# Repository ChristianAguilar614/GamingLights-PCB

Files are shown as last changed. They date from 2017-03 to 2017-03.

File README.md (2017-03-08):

# GamingLights-PCB
Arduino Nano Shield

Circuit utilizes the compact size of the Arduino Nano to round appropriate light controllers. This works as an accent lighting system with RGB custimization. 
MOSFET drivers help boost the current and voltage which will be used to amplifier the overall wattage of the system to support 24 watts

#3d View
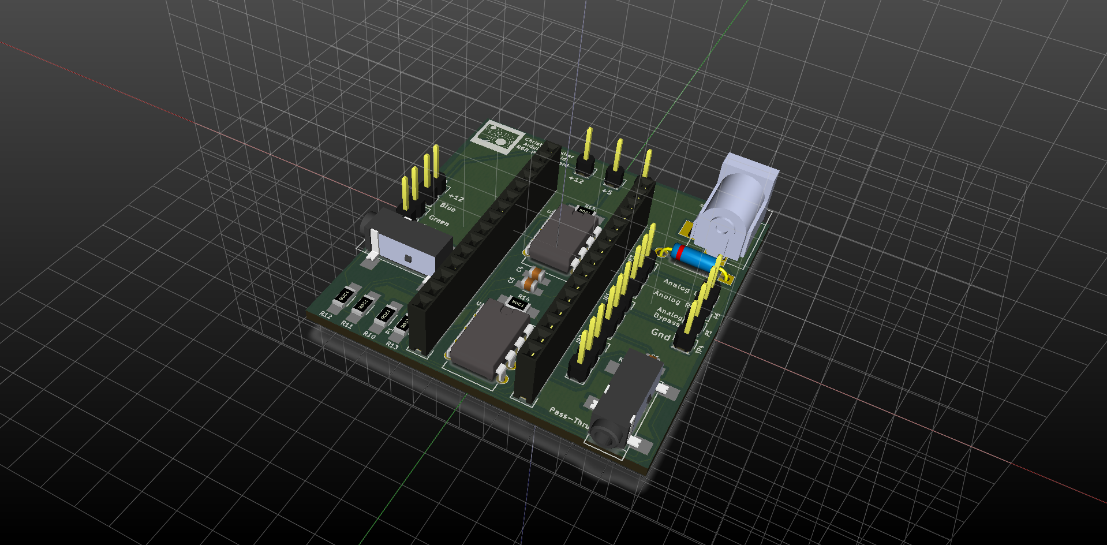
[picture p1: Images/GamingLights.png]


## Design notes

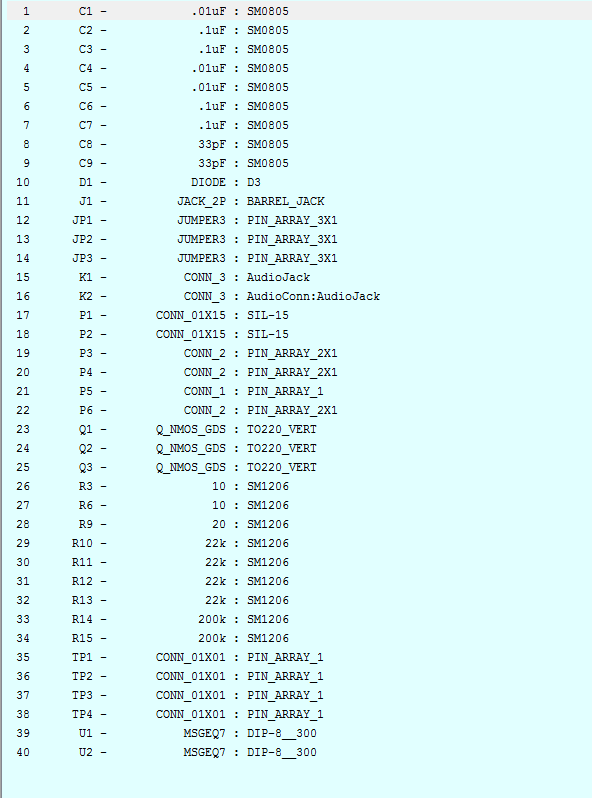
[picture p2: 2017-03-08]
Images/Comp2Part.PNG

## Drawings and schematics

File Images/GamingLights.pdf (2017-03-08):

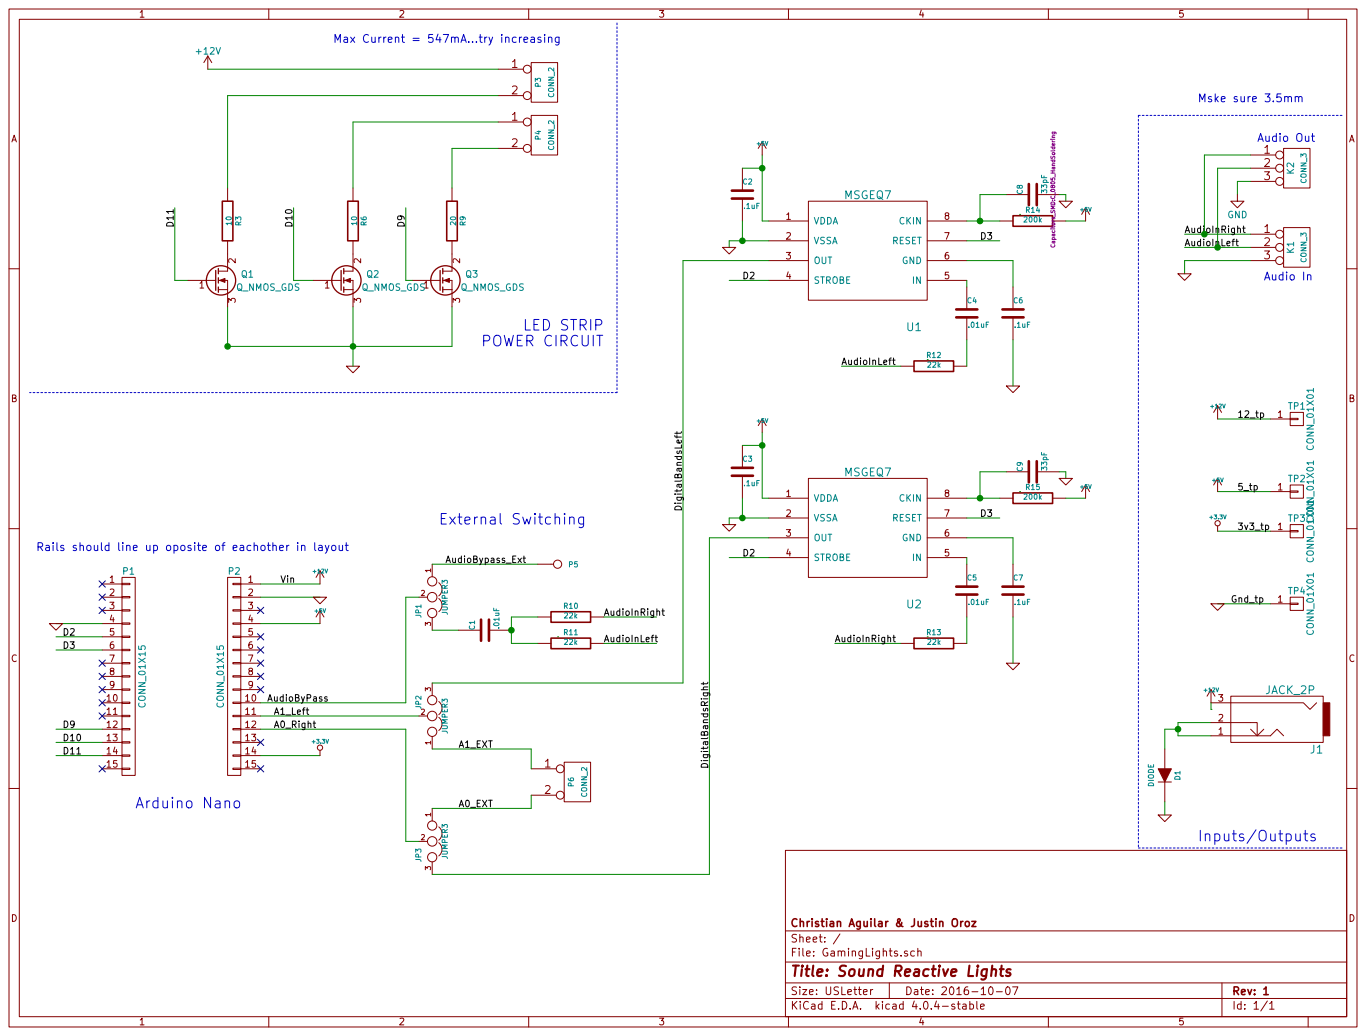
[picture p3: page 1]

Max Current = 547mA...try increasing

Audio Out Audio In GND

Id: 1/1 Title: Sound Reactive Lights

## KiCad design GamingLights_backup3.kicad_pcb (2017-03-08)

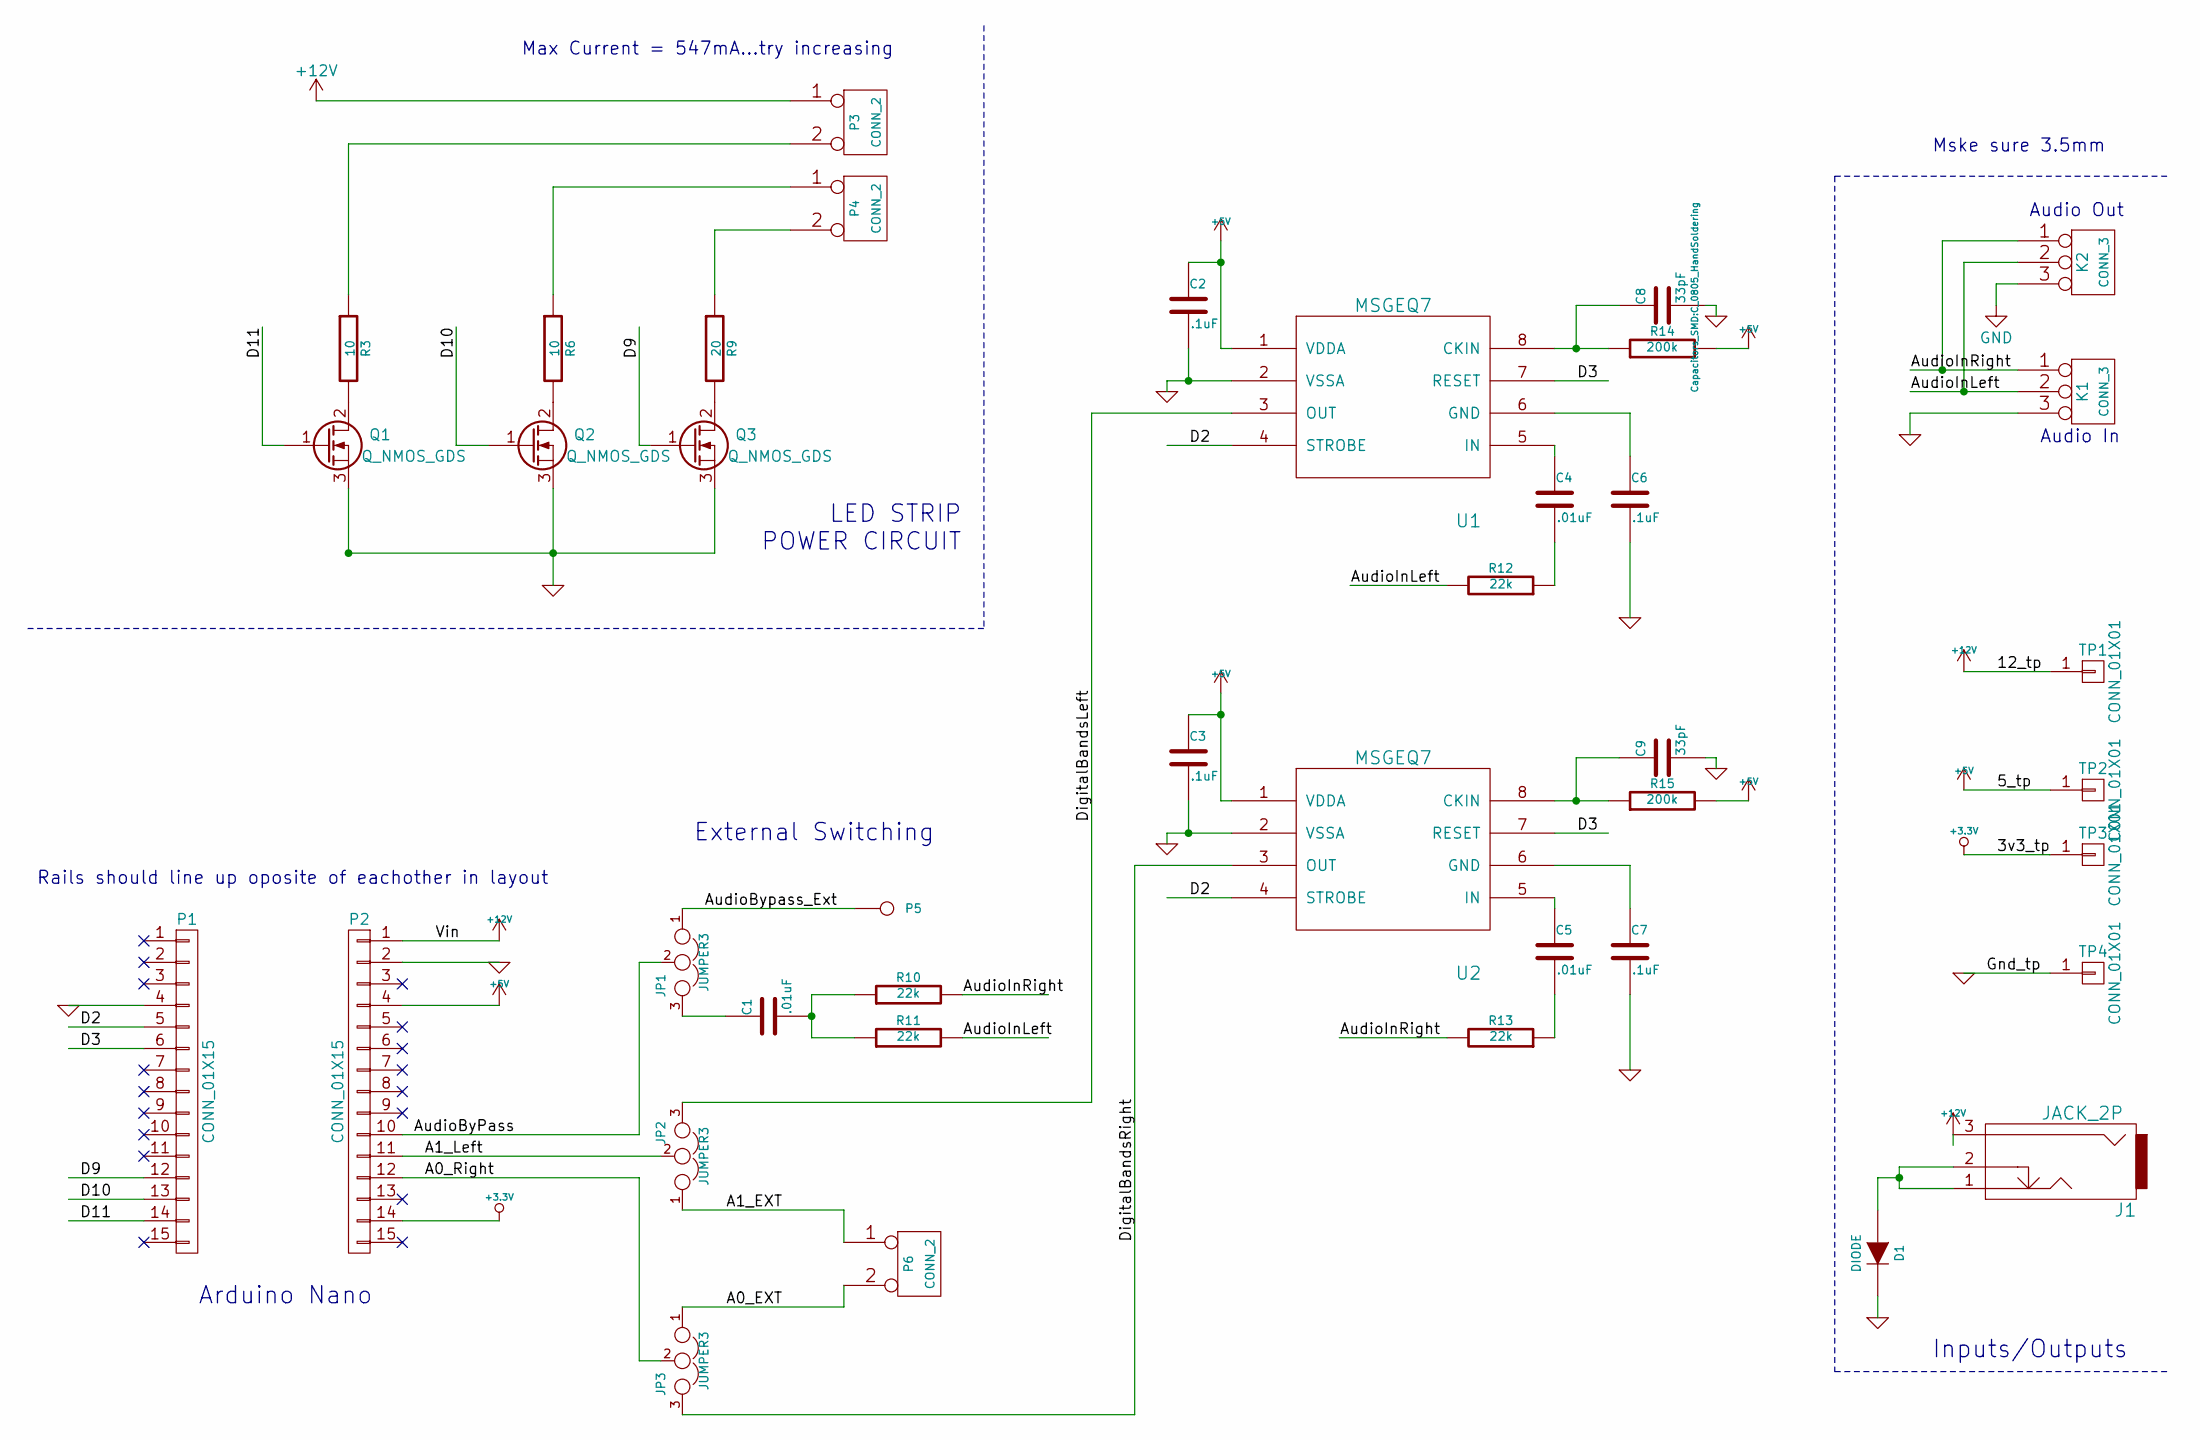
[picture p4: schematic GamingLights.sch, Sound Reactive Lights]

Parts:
C1, C4, C5: .01uF; C_0805_HandSoldering
C2, C3, C6, C7: .1uF; C_0805_HandSoldering
C8, C9: 33pF; C_0805_HandSoldering
D1: DIODE; Diode_DO-41_SOD81_Horizontal_RM10
J1: JACK_2P; BARREL_JACK
JP1, JP2, JP3: JUMPER3; Pin_Header_Straight_1x03
K1, K2: CONN_3; AudioJack
P1, P2: CONN_01X15; Socket_Strip_Straight_1x15
P3, P4, P6: CONN_2; Pin_Header_Straight_1x02
P5: CONN_1; Pin_Header_Straight_1x01
Q1, Q2, Q3: Q_NMOS_GDS; SOT-223
R3, R6: 10; R_1206_HandSoldering
R9: 20; R_1206_HandSoldering
R10, R11, R12, R13: 22k; R_1206_HandSoldering
R14, R15: 200k; R_1206_HandSoldering
TP1, TP2, TP3, TP4: CONN_01X01; Pin_Header_Straight_1x01
U1, U2: MSGEQ7; DIP-8_W7.62mm

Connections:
+3.3V: P2.14, TP3.1
+5V: C2.1, C3.1, P2.4, R14.2, R15.2, TP2.1, U1.1 (VDDA), U2.1 (VDDA)
+12V: J1.3, P2.1, P3.1, TP1.1
/A0_EXT: JP3.1, P6.2 (PM)
/A0_Right: JP3.2, P2.12
/A1_EXT: JP2.1, P6.1
/A1_Left: JP2.2, P2.11
/AudioByPass: JP1.2, P2.10
/AudioBypass_Ext: JP1.1, P5.1
/AudioInLeft: K1.2 (PM), K2.2 (PM), R11.2, R12.2
/AudioInRight: K1.1, K2.1, R10.2, R13.2
/D2: P1.5, U1.4 (STROBE), U2.4 (STROBE)
/D3: P1.6, U1.7 (RESET), U2.7 (RESET)
/D9: P1.12, Q3.1 (G)
/D10: P1.13, Q2.1 (G)
/D11: P1.14, Q1.1 (G)
/DigitalBandsLeft: JP2.3, U1.3 (OUT)
/DigitalBandsRight: JP3.3, U2.3 (OUT)
GND: C2.2, C3.2, C6.2, C7.2, C8.2, C9.2, D1.2 (K), K1.3, K2.3, P1.4, P2.2, Q1.3 (S), Q2.3 (S), Q3.3 (S), TP4.1, U1.2 (VSSA), U2.2 (VSSA)
unnamed: C1.1, JP1.3
unnamed: C1.2, R10.1, R11.1
unnamed: C4.1, U1.5 (IN)
unnamed: C4.2, R12.1
unnamed: C5.1, U2.5 (IN)
unnamed: C5.2, R13.1
unnamed: C6.1, U1.6 (GND)
unnamed: C7.1, U2.6 (GND)
unnamed: C8.1, R14.1, U1.8 (CKIN)
unnamed: C9.1, R15.1, U2.8 (CKIN)
unnamed: D1.1 (A), J1.1, J1.2
unnamed: P3.2 (PM), R3.1
unnamed: P4.1, R6.1
unnamed: P4.2 (PM), R9.1
unnamed: Q1.2 (D), R3.2
unnamed: Q2.2 (D), R6.2
unnamed: Q3.2 (D), R9.2

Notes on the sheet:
LED STRIP POWER CIRCUIT
Arduino Nano
Inputs/Outputs
External Switching
Audio Out
Audio In
Rails should line up oposite of eachother in layout
Mske sure 3.5mm
Max Current = 547mA...try increasing

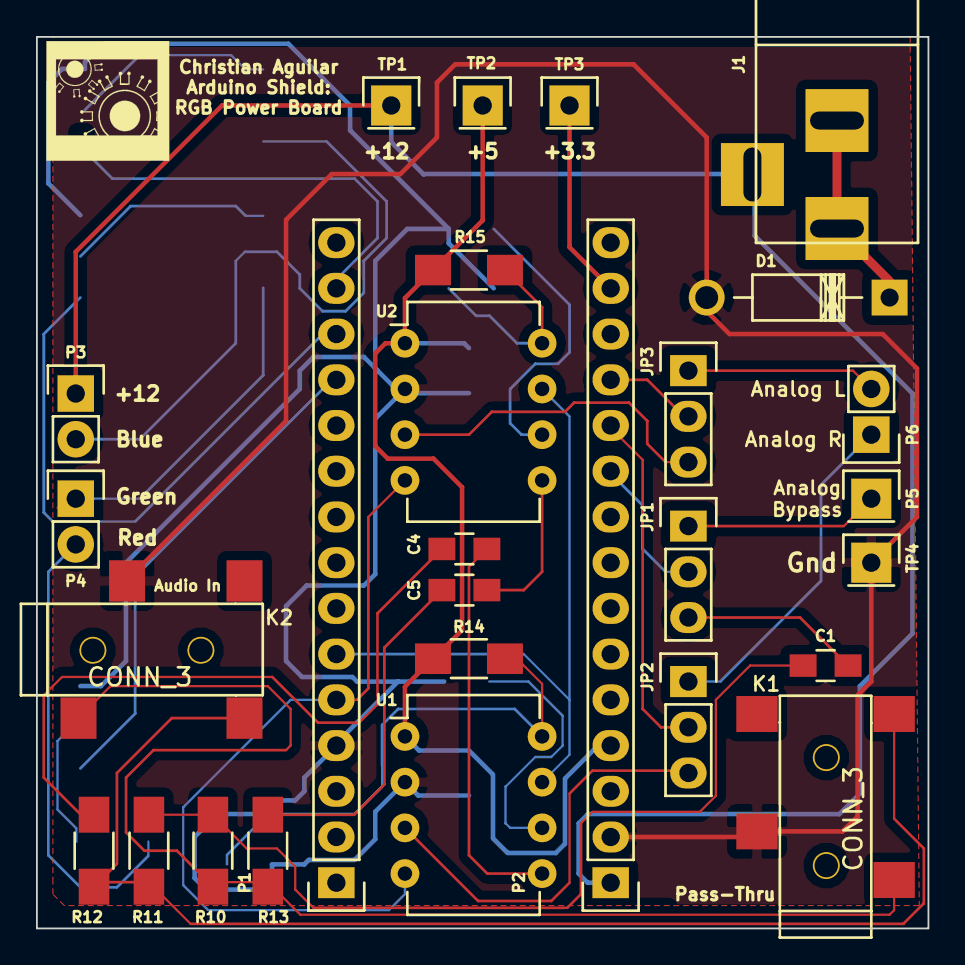
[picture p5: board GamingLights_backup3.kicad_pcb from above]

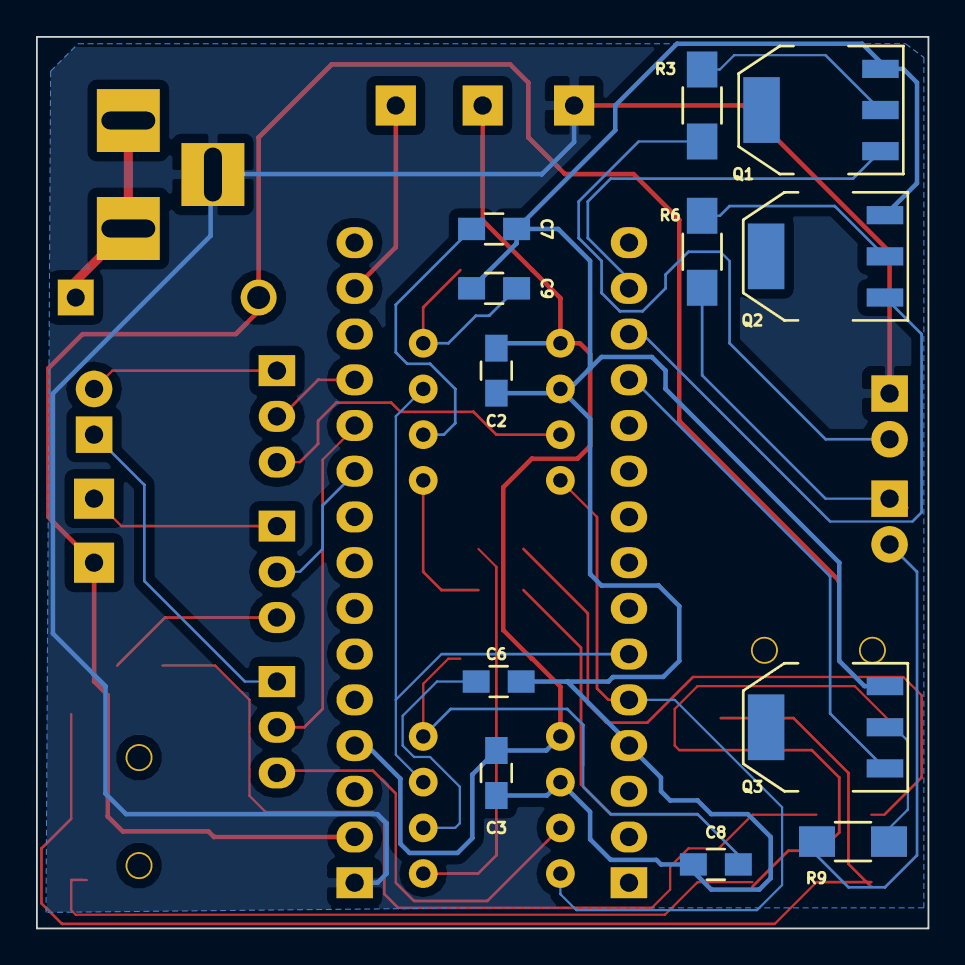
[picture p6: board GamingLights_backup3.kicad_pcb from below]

Board: 2 copper layers, 49.5 x 49.5 mm, 40 parts (12 on the bottom side), 36 nets.

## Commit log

2017-03-08 Initial Upload
    [BOM.xlsx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]
2017-03-09 Unnecessary files deleted
    [BOM.xlsx]
